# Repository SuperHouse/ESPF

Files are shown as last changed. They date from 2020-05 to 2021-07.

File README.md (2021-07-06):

ESPFlasher ESP8266 / ESP32 Programmer
======================================

Serial programming adapter for the Espressif ESP8266 and ESP32 with
a USB-C connection. Provides a 6-pin connection that includes power,
TX, RX, and the GPIO0 / Reset lines required to put the ESPx into
programming mode.

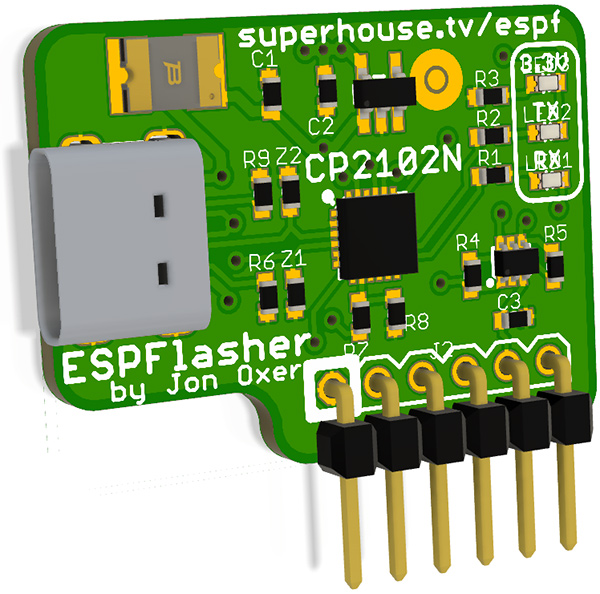
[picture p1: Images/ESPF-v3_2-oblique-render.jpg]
ESP Flasher PCB render


The pinout is compatible with the "ESPFlash" header convention:

  https://www.superhouse.tv/espflash

Features:

 * USB-C interface for connection to host.
 * ESPFlash 1x6 0.1" header for connection to target board.
 * CP2102N USB-to-serial converter.
 * TX/RX LEDs.
 * 600mA 3.3V voltage regulator to power target board.

You can view more details at:

  https://www.superhouse.tv/espf

Credits
-------
 * Jonathan Oxer <jon@oxer.com.au>

License
-------
Copyright 2019-2020 Superhouse Automation Pty Ltd www.superhouse.tv

The hardware portion of this project is licensed under the TAPR Open
Hardware License (www.tapr.org/OHL). The "license" folder within this
repository also contains a copy of this license in plain text format.

The software portion of this project is licensed under the Simplified
BSD License. The "licence" folder within this project contains a copy
of this license in plain text format.

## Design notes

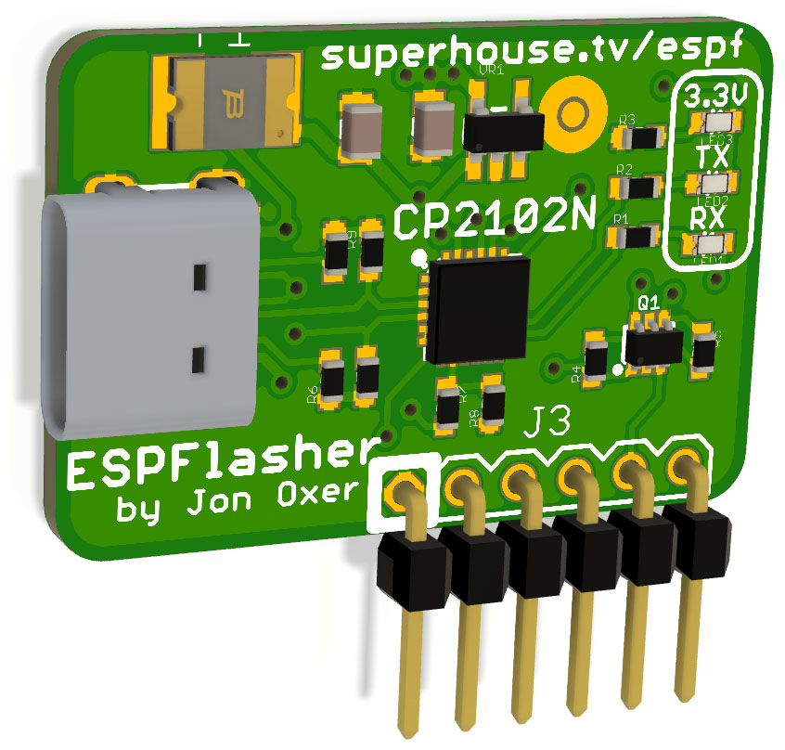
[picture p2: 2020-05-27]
Images/ESPF-v3_0-oblique-render.jpg

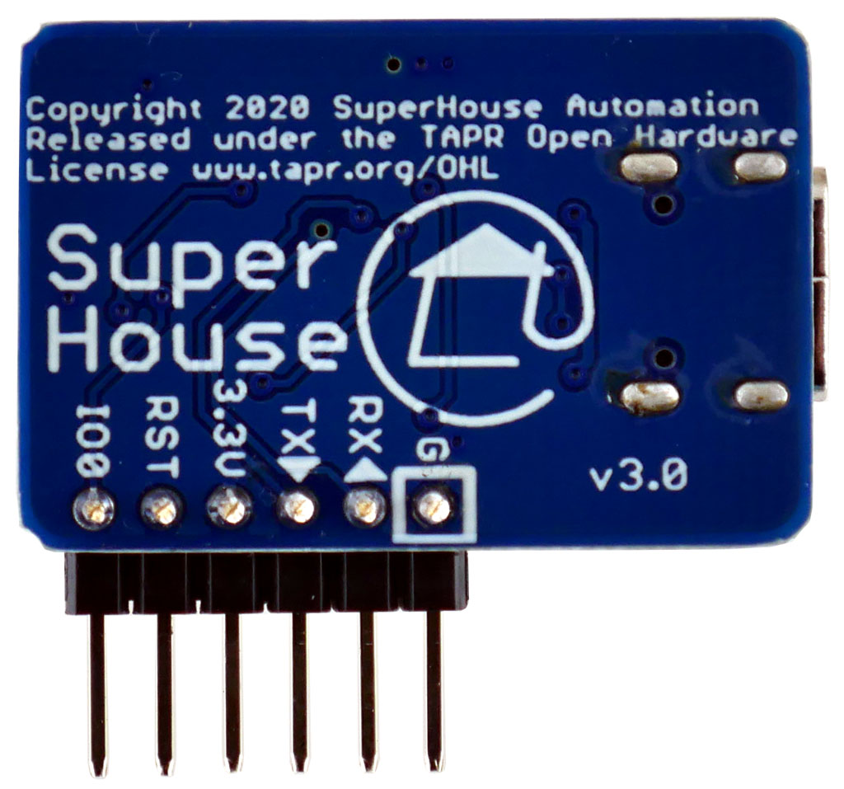
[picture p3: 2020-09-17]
Images/ESPF-v3_0-back.jpg

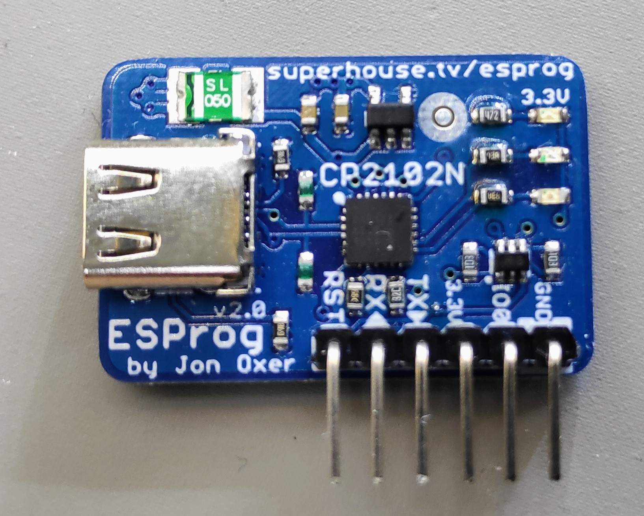
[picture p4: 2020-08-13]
Images/2019-09-15 21.19.14.jpg

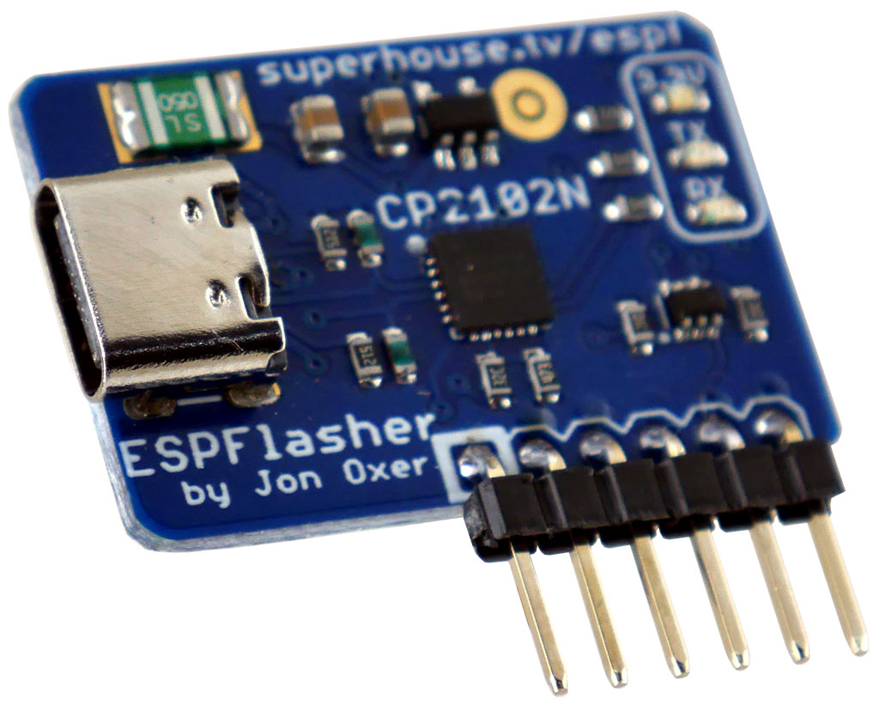
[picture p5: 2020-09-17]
Images/ESPF-v3_0-oblique.jpg

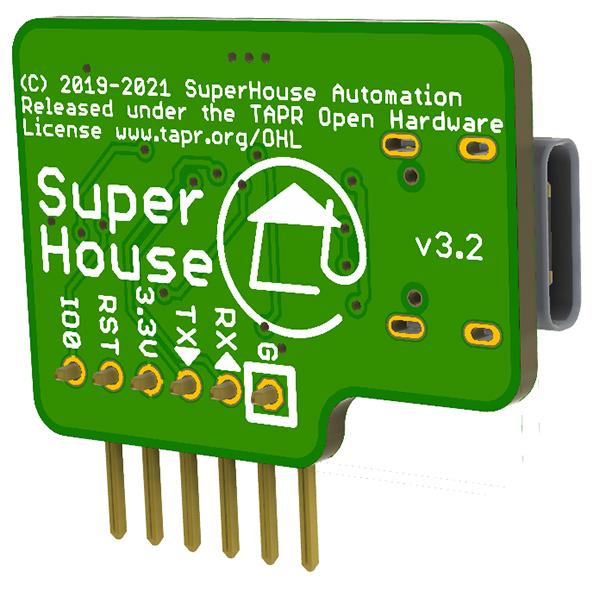
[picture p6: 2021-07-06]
Images/ESPF-v3_2-oblique-render-back.jpg

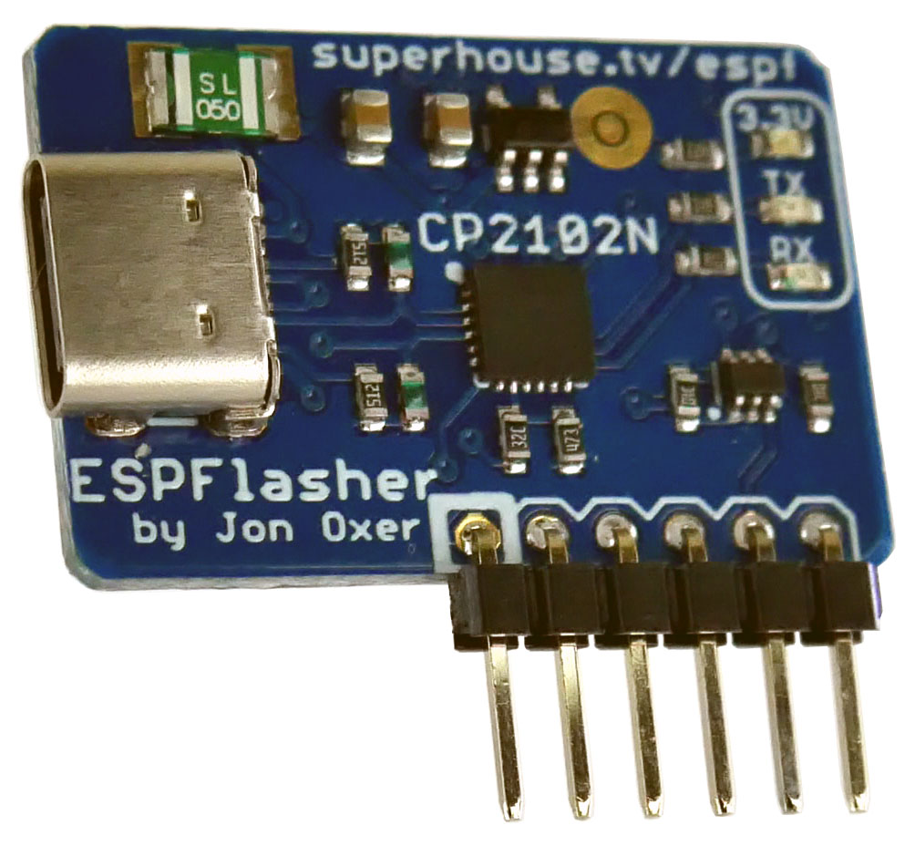
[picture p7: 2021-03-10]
Images/ESPF-v3_0-oblique-2.jpg

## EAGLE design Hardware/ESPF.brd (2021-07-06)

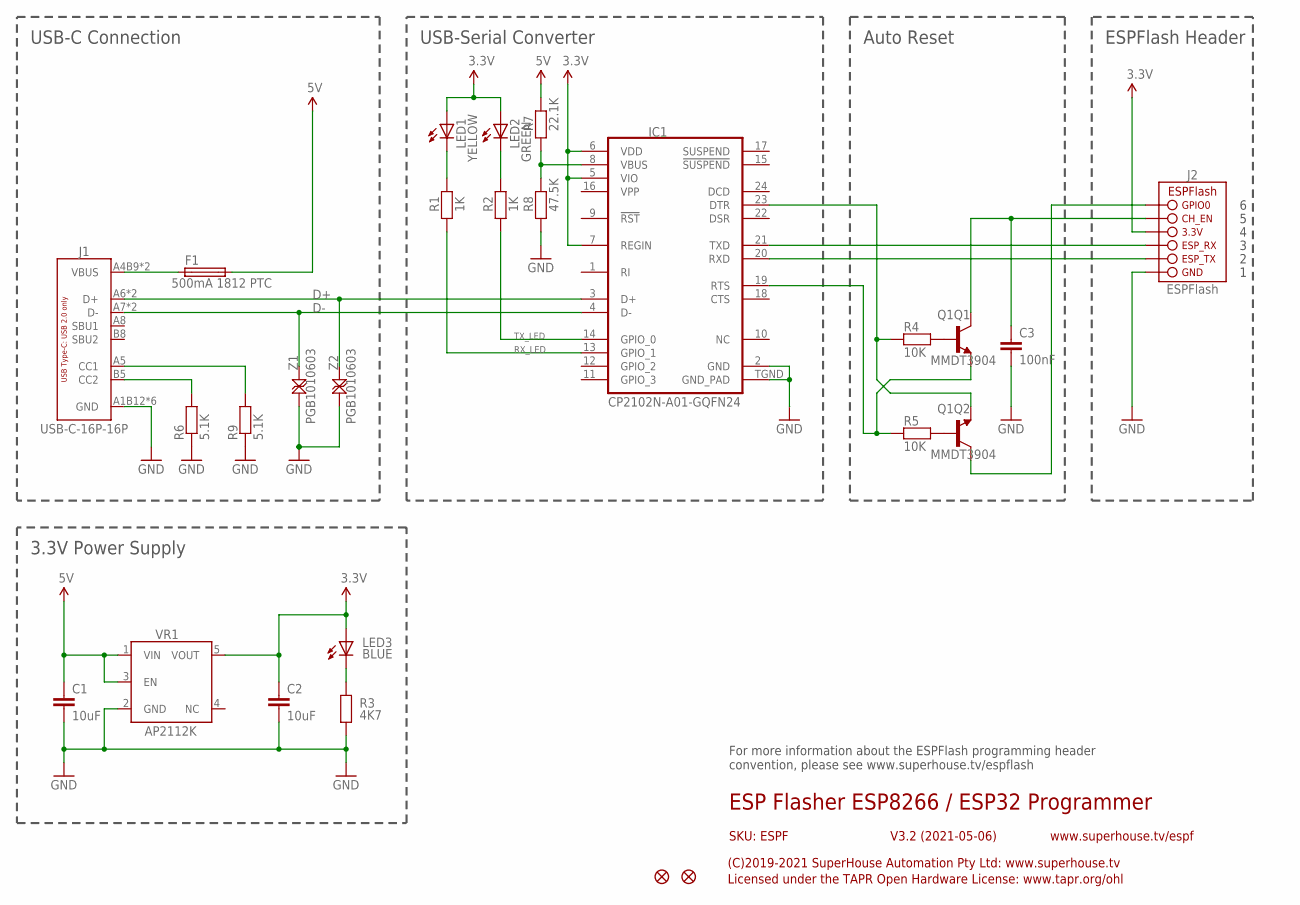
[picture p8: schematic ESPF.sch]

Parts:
C1, C2: 10uF; C0603
C3: 100nF; C0603
F1: 500mA 1812 PTC; 1812
FID1, FID2: FIDUCIAL1X2.5; FIDUCIAL-1X2.5
IC1: CP2102N-A01-GQFN24; QFN-24
J1: USB-C-16P-16P; USB-C-16P
J2: ESPFLASH-1X6-2.54-PINS-RA; 1X6-2.54-PINS-RA
LED1: YELLOW; LED-0603
LED2: GREEN; LED-0603
LED3: BLUE; LED-0603
Q1: MMDT3904; SOT-363
R1, R2: 1K; R0603
R3: 4K7; R0603
R4, R5: 10K; R0603
R6, R9: 5.1K; R0603
R7: 22.1K; R0603
R8: 47.5K; R0603
VR1: AP2112K-3.3; SOT23-5
Z1, Z2: PGB1010603; TVS0603

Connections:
3.3V: C2.1, IC1.5 (VIO), IC1.6 (VDD), IC1.7 (REGIN), J2.4 (3.3V), LED1.A, LED2.A, LED3.A, VR1.5 (VOUT)
5V: C1.1, F1.2, R7.2, VR1.1 (VIN), VR1.3 (EN)
D+: IC1.3 (D+), J1.A6 (D+), J1.B6 (D+), Z2.2
D-: IC1.4 (D-), J1.A7 (D-), J1.B7 (D-), Z1.2
DTR: IC1.23 (DTR), Q1.1 (E), R4.1
EN: C3.1, J2.5 (CH_EN), Q1.3 (C)
GND: C1.2, C2.2, C3.2, IC1.2 (GND), IC1.TGND (GND_PAD), J1.A1B12 (GND), J1.A12B1 (GND), J1.FIX1 (GND), J1.FIX2 (GND), J1.FIX3 (GND), J1.FIX4 (GND), J2.1 (GND), R3.1, R6.1, R8.1, R9.1, VR1.2 (GND), Z1.1, Z2.1
GPIO0: J2.6 (GPIO0), Q1.6 (C)
unnamed: LED1.C, R1.2
unnamed: LED2.C, R2.2
unnamed: LED3.C, R3.2
unnamed: IC1.8 (VBUS), R7.1, R8.2
unnamed: Q1.5 (B), R4.2
unnamed: Q1.2 (B), R5.2
unnamed: J1.B5 (CC2), R6.2
unnamed: J1.A5 (CC1), R9.2
RTS: IC1.19 (RTS), Q1.4 (E), R5.1
RXI: IC1.20 (RXD), J2.2 (ESP_TX)
RX_LED: IC1.13 (GPIO_1), R1.1
TXO: IC1.21 (TXD), J2.3 (ESP_RX)
TX_LED: IC1.14 (GPIO_0), R2.1
VIN: F1.1, J1.A4B9 (VBUS), J1.A9B4 (VBUS)

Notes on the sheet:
ESP Flasher ESP8266 / ESP32 Programmer
V3.2 (2021-05-06)
SKU: ESPF
(C)2019-2021 SuperHouse Automation Pty Ltd: www.superhouse.tv
Licensed under the TAPR Open Hardware License: www.tapr.org/ohl
www.superhouse.tv/espf
USB-C Connection
USB-Serial Converter
Auto Reset
ESPFlash Header
3.3V Power Supply
For more information about the ESPFlash programming header convention, please see www.superhouse.tv/espflash

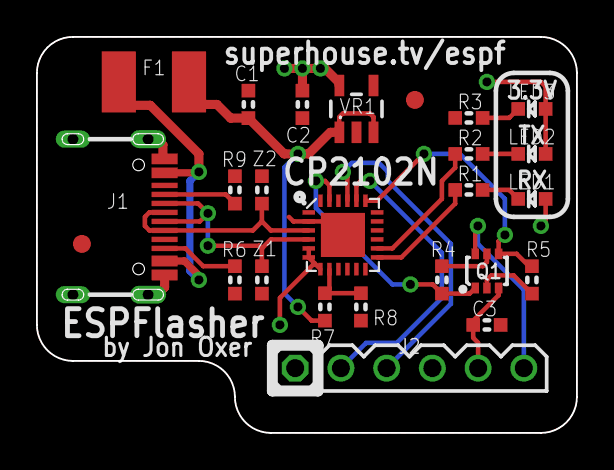
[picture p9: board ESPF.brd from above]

Board: 2 copper layers, 30.0 x 22.0 mm, 25 parts (0 on the bottom side), 22 nets.

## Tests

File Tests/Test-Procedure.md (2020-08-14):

ESP-Flasher Test Procedure
==========================

Open Simplicity Studio.

Select CP2102N as the device type.

Important settings:

 * Max Power (mA) = 500
 * Power Mode = Bus Powered
 * Port Drive Strength = High Drive
 * DTR: Reset Mode = Push-Pull
 * RTS: Reset Mode = Push-Pull
 * GPIO0: Reset Mode = Push-Pull, Alternate Function = TX Toggle
 * GPIO1: Reset Mode = Push-Pull, Alternate Function = RX Toggle

Plug in device using USB-C cable.

Click "Program To Device". Process takes approximately 5.3 seconds.

Disconnect USB-C cable.

Reconnect USB-C cable.

Plug in a working board with an ESPFlash header.

In terminal, run command:

    esptool.py -p /dev/tty.SLAB_USBtoUART flash_id

Observe:

 * Both TX and RX LEDs illuminate.
 * Target board resets.
 * Terminal reports the device ID, memory, etc of the working board.

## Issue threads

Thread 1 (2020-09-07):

Minor errors in the readme and possible improvements

2010019970909, 2020-09-07:
Hello,

There is an error in the spelling of the chip name.

``CP2012N USB-to-serial converter`` instead of ``CP2102N USB-to-serial converter.``
And last line ``capy`` instead of ``copy``

Also the link to https://www.superhouse.tv/espf is leading to nothing.

I did not go in depth in your project but maybe you should consider to change the voltage regulator for an [AMS-1117 3.3V](http://www.advanced-monolithic.com/pdf/ds1117.pdf) (I think it's adviced in the ESP32 datasheet to use a 3.3V voltage regulator that can deliver 1A or more).

Also a zip with the gerber files as a release could be a plus (I don't know with EDA you did use) as well as the BOM list to replicate the project.

You have a very nice project ;-)

Have a nice day,

Vincent

jonoxer, 2020-09-08:
Thanks for your help, Vincent! I didn't notice those mistakes. I'll fix them now.

I use the AMS1117 in many of my other projects, but it's an old chip with poor specs compared to newer ones like the AP2112. The AP2112 is *much* better than the AMS1117 in every single spec except for peak current rating, and it's about 1/8th the size. In fact the voltage overhead of the AMS1117 means that it's operating only 0.55V away from the limits of its spec when supplying 3.3V from a 5V power source, which is a small margin for error.

I've used the AP2112 on many ESPxx projects and never had a problem with the peak current rating.

The design files can be opened in either EAGLE or Fusion 360, which can be used to generate production files to suit the design rules for the factory that will make the boards, including the bill of materials. I don't find that generic Gerber files are much use and I always generate them to suit the factory, so I don't bother including them with my projects. Anyone who wants to fabricate the boards will probably need to generate their own Gerbers anyway.

The URL is broken because I haven't released this project yet. It's still a draft, and I need to make the page for it.

Cheers :-)

Jon

Closed 2020-09-08.

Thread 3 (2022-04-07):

Brownout detector was triggered

ilium007, 2022-04-07:
Specs say that the ESPFlasher has a 600mA voltage regulator on board. How can I be getting a brownout reboot loop when using the ESPFlasher on an Adafruit Huzzah32 ESP32 board when connected trying to access serial console?

```
Rebooting...
ets Jun  8 2016 00:22:57

rst:0xc (SW_CPU_RESET),boot:0x13 (SPI_FST_FLSH_BOOT)
configsip: 0, SPIWP:0xee
clk_drv:0x00,q_drv:0x00,d_drv:0x00,cs0_drv:0x00,hd_drv:0x00,wp_drv:0x00
mode:DIO, clock div:2
load:0x3fff0018,len:4
load:0x3fff001c,len:1044
load:0x40078000,len:8896
load:0x40080400,len:5828
entry 0x400806ac
Connecting to WiFi (24:6F:28:3:2:00)...

Brownout detector was triggered

ets Jun  8 2016 00:22:57

rst:0xc (SW_CPU_RESET),boot:0x13 (SPI_FST_FLSH_BOOT)
configsip: 0, SPIWP:0xee
clk_drv:0x00,q_drv:0x00,d_drv:0x00,cs0_drv:0x00,hd_drv:0x00,wp_drv:0x00
mode:DIO, clock div:2
load:0x3fff0018,len:4
load:0x3fff001c,len:1044
load:0x40078000,len:8896
load:0x40080400,len:5828
entry 0x400806ac
Connecting to WiFi (24:6F:28:3:2:00)...
```

austinscreations, 2022-04-07:
600mA can be on the low side of things, it's likely that at the peak of booting it might be experiencing a brief drop in voltage. which initial connection to wifi can do.

also that board has onboard usb with builtin USB-to-Serial converter. why use an external flasher?
and the 3v pin on the board isn't listed as an input but rather an output of the onboard regulator. which may also be causing issues

ilium007, 2022-04-08:
It’s the Adafruit Huzzah32 Development board. No USB. And you can feed in on the voltage regulator output. Done it for years.

ilium007, 2022-04-08:
I’ve also tried feeding the onboard 5v regulator from a bench top lab power supply. The log does not show brownout reboot. It’s the same error that  others have logged here in the issues.

austinscreations, 2022-04-08:
my bad, didn't realize they sold one without usb.

my only thought would be a power issue. but you've indicated you've tried a bench power supply so i'm at a loss.

my best suggestion would be to join the superhouse discord and ask / post photos of your setup there and people there can likely help troubleshoot more.

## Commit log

2019-06-21 Initial project import for v1.0 release
    [ESPROG.brd, ESPROG.sch]
2019-06-21 Renumbered parts
    [ESPROG.brd, ESPROG.sch]
2019-07-01 Replaced most parts using SuperHouse library to add 3D models
    [ESPROG.brd]
2019-07-04 Improved designators
    [ESPROG.brd]
2019-07-04 Replaced CP2104 with CP2102N for v1.1 release
    [ESPROG.brd, ESPROG.sch]
2019-07-07 Split CC1 and CC2 on USB connector
    [ESPROG.brd, ESPROG.sch]
2020-05-25 Major revision of header pinout
    [ESPROG.brd, ESPROG.sch]
2020-05-25 Updated README and render for raname and v3.0
    [ESPF.brd, ESPF.sch]
2020-05-27 Fixed dimensions of 6-way right angle header
    [ESPF.brd, ESPF.sch]
2020-08-13 Begin restructuring project
    [ESPF.brd, ESPF.sch]
2021-03-10 Replace ESPFlash header using part from dedicated library.
    [ESPF.brd, ESPF.sch]
2021-07-06 Added 100nF cap on reset line of target device. Added tab to support right angle header. Added note about ESPFlash convention in schematic.
    [ESPF.brd, ESPF.sch]
2021-07-06 Added schematic of PDF for release v3.2.
